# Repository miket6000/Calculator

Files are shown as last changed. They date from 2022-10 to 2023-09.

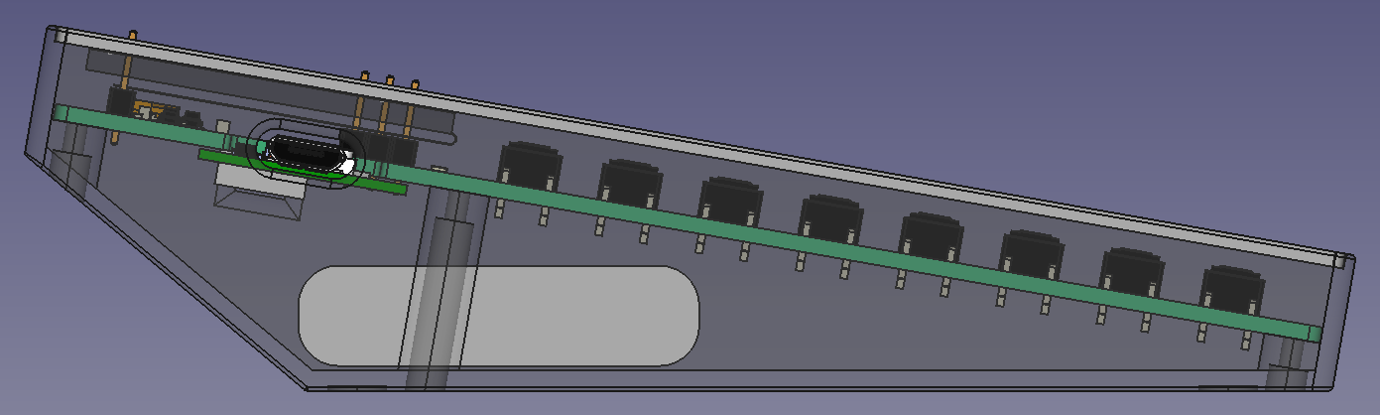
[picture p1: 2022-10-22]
LeftView.png

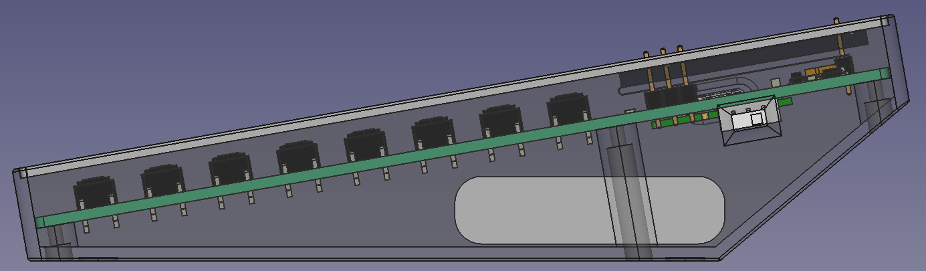
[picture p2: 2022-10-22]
RightView.png

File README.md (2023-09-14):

# Calculator
This calculator was built to scratch an itch. I wanted a physical RPN calculator similar to the excellent RealCalc. I also wanted an excuse to play around with a pi pico, particuarly their PIO. Finally I wanted a hardware platform to allow me to tinker in firmware and SW as I had ideas and wanted to try something out.

vanity shot

## Status
### Electrical
The PCB is great all circuits have been tested and I'm not aware of any issues. I'm very impressed with the OLED display (photographing it is hard). 

The pico's lowest standby power is only so-so, I can get down to about 980uA which with the 2500mA battery last around 3 months between charges if you only use standby and not the power switch (and significantly less time if the display is left on).

### Mechanical
The 3d printed enclosure and OLED support are perfectly functional, however I wouldn't mind adding more support in the center of the PCB to help dampen some of the button click noise. 

The front panel is a little iffy. The text is too small to easily read, there's not really enough room to make it larger. I also didn't properly consider the mounting so while I did design it with an assembly method in mind, and it does work, there's room for improvement.

### Software
The software is in a good demonstration state. Standby has been implemented to allow low power measurements. The display drivers and basic screen & keyboard abstraction layers have been created as has the skelaton of the ALU. So today you can use it as a basic pocket calculator. This is only a fraction of what I had planned though. 

I wanted to create a macro system so you could record common equations and adjust the variables you want. There's also a softkey function which so far is barely implemented. One softkey is used to put the calculator into standby, the others need defining and a proper system for assigning actions to the soft keys needs to be built.

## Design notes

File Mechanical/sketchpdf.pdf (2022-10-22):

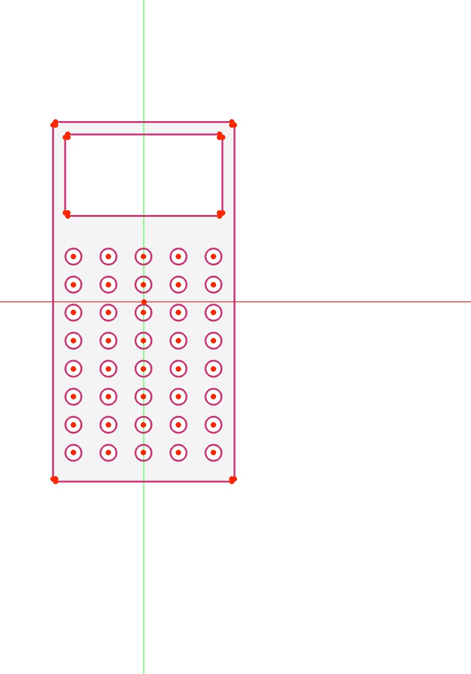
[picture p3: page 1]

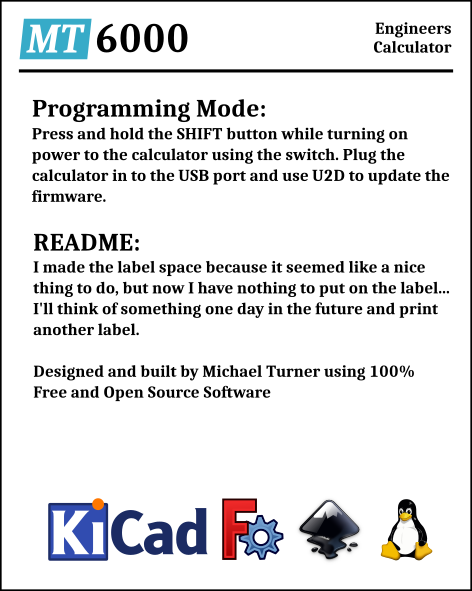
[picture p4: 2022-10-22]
Mechanical/Label.png

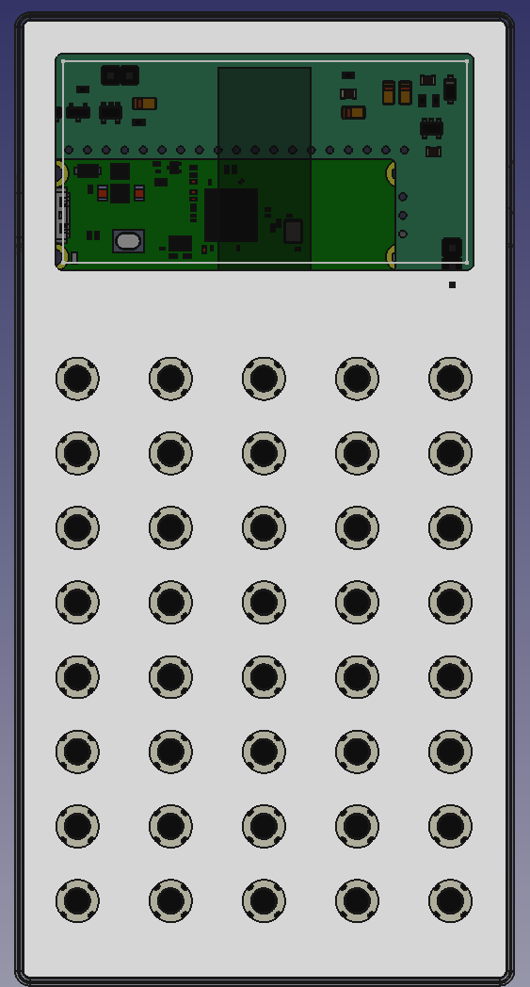
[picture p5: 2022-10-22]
FrontView.png

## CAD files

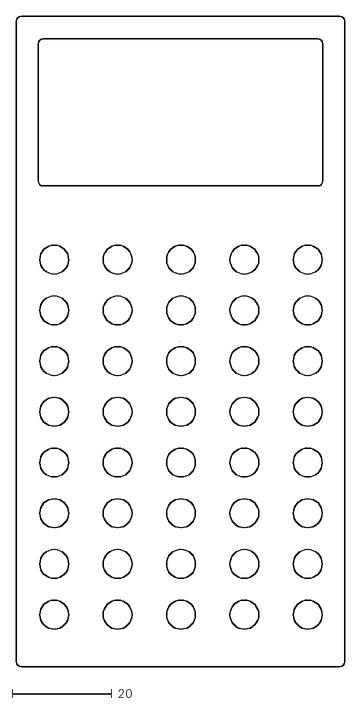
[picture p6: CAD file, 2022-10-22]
FrontPanel/outline.dxf
65.8 x 130.3

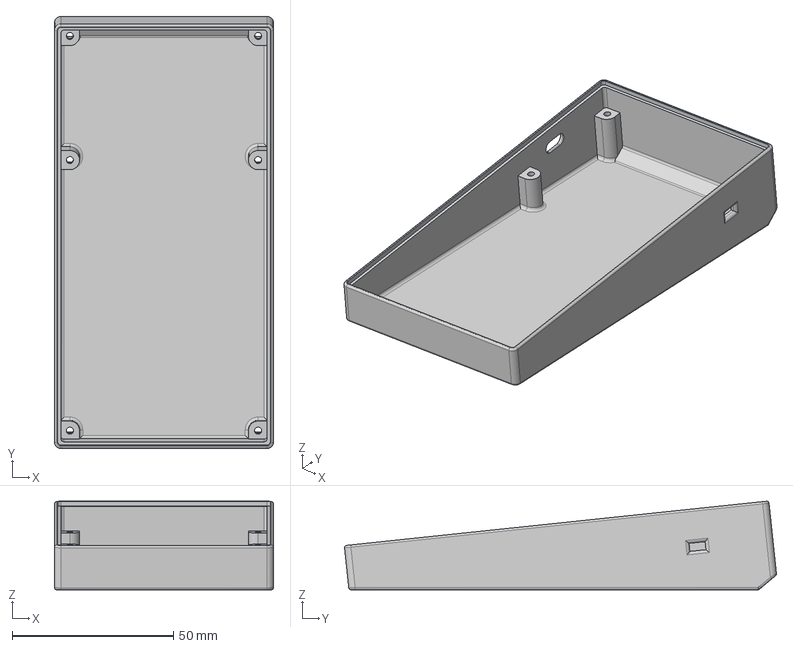
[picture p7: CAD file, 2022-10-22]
Mechanical/Calculator-Housing.step
68.0 x 134.1 x 27.5 mm

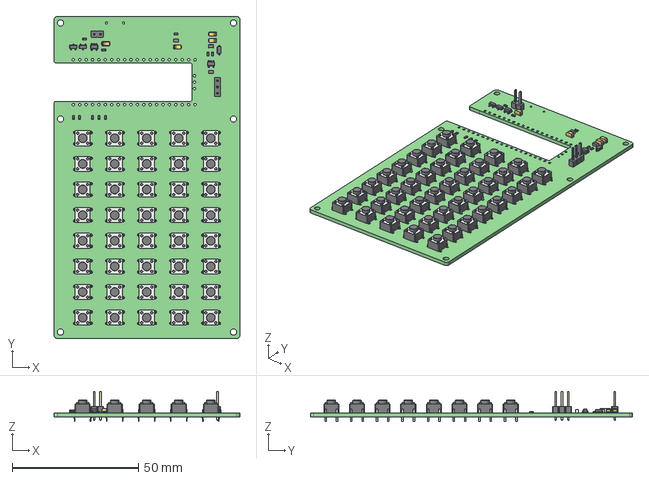
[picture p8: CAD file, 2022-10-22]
ThinCalculator.step
73.7 x 127.6 x 12.0 mm
_autosave-ThinCalculator PCB

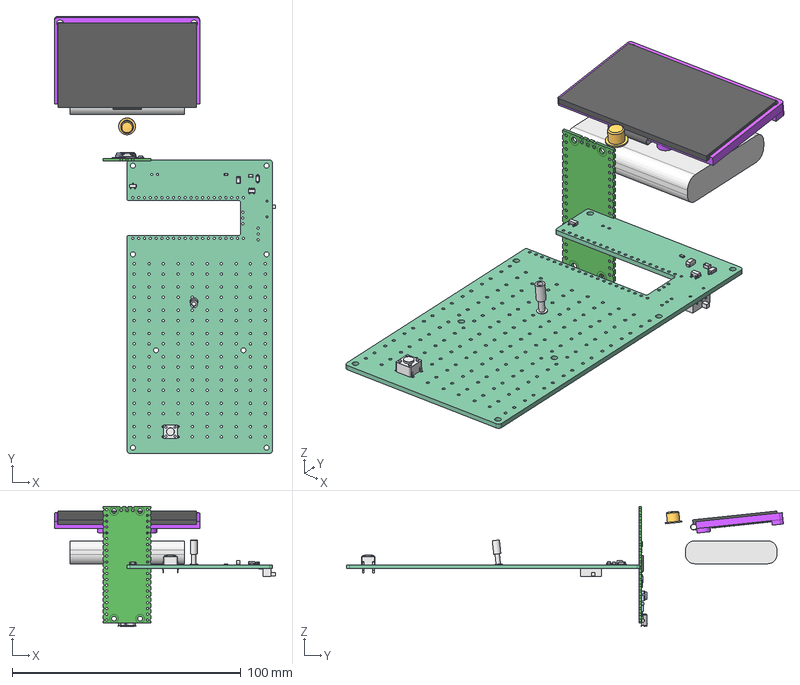
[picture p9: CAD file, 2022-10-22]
Mechanical/Calculator.FCStd
96.6 x 190.9 x 52.4 mm
Screen
Button
Screw
Battery
Standoff
ScreenSupport
PCB, Raspberry Pi Pico-R3
MicroUSB Port, Raspberry Pi Pico-R3
MicroUSB Port, Raspberry Pi Pico-R004
MicroUSB Port, Raspberry Pi Pico-R005
MicroUSB Port, Raspberry Pi Pico-R006
MicroUSB Port, Raspberry Pi Pico-R007
MicroUSB Port, Raspberry Pi Pico-R008
MicroUSB Port, Raspberry Pi Pico-R009
RP2040 Microcontroller, Raspberry Pi Pico-R3
SW1, Tact Switch, Raspberry Pi Pico-R3
D1, Diode, Schottky, Raspberry Pi Pico-R3
D2, QSME-C194, LED, Raspberry Pi Pico-R3
L1, Inductor, Raspberry Pi Pico-R3
U2, RT6150B-33GQW, Buck Boost Converter, Raspberry Pi Pico-R3
U3, W25Q16JVUXIQ, Serial NOR Flash 16 Mbit, Raspberry Pi Pico-R3
Q1, MOSFET, DMG1012T, Raspberry Pi Pico-R3
X1, X12M000000S096, 12 Mhz Crystal Resonator, Raspberry Pi Pico-R3
SMD Resistor, Configurable, Raspberry Pi Pico-R3_R1
SMD Resistor, Configurable, Raspberry Pi Pico-R3_R002
SMD Resistor, Configurable, Raspberry Pi Pico-R3_R003
SMD Resistor, Configurable, Raspberry Pi Pico-R3_R2
SMD Resistor, Configurable, Raspberry Pi Pico-R3_R005
SMD Resistor, Configurable, Raspberry Pi Pico-R3_R006
SMD Resistor, Configurable, Raspberry Pi Pico-R3_R3
SMD Resistor, Configurable, Raspberry Pi Pico-R3_R008
SMD Resistor, Configurable, Raspberry Pi Pico-R3_R009
SMD Resistor, Configurable, Raspberry Pi Pico-R3_R4
SMD Resistor, Configurable, Raspberry Pi Pico-R3_R011
SMD Resistor, Configurable, Raspberry Pi Pico-R3_R012
SMD Resistor, Configurable, Raspberry Pi Pico-R3_R5
SMD Resistor, Configurable, Raspberry Pi Pico-R3_R014
SMD Resistor, Configurable, Raspberry Pi Pico-R3_R015
SMD Resistor, Configurable, Raspberry Pi Pico-R3_R6
SMD Resistor, Configurable, Raspberry Pi Pico-R3_R017
SMD Resistor, Configurable, Raspberry Pi Pico-R3_R018
SMD Resistor, Configurable, Raspberry Pi Pico-R3_R7
SMD Resistor, Configurable, Raspberry Pi Pico-R3_R020
SMD Resistor, Configurable, Raspberry Pi Pico-R3_R021
SMD Resistor, Configurable, Raspberry Pi Pico-R3_R8
SMD Resistor, Configurable, Raspberry Pi Pico-R3_R023
SMD Resistor, Configurable, Raspberry Pi Pico-R3_R024
SMD Resistor, Configurable, Raspberry Pi Pico-R3_R9
SMD Resistor, Configurable, Raspberry Pi Pico-R3_R026
SMD Resistor, Configurable, Raspberry Pi Pico-R3_R027
SMD Resistor, Configurable, Raspberry Pi Pico-R3_R10
SMD Resistor, Configurable, Raspberry Pi Pico-R3_R029
SMD Resistor, Configurable, Raspberry Pi Pico-R3_R030
SMD Resistor, Configurable, Raspberry Pi Pico-R3_R11
SMD Resistor, Configurable, Raspberry Pi Pico-R3_R032
SMD Resistor, Configurable, Raspberry Pi Pico-R3_R033
SMD Resistor, Configurable, Raspberry Pi Pico-R3_R12
SMD Resistor, Configurable, Raspberry Pi Pico-R3_R035
SMD Resistor, Configurable, Raspberry Pi Pico-R3_R036
SMD Resistor, Configurable, Raspberry Pi Pico-R3_R13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

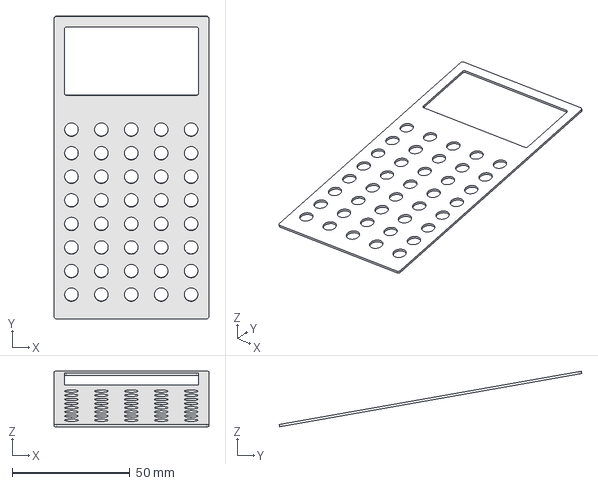
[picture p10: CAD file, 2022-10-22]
Mechanical/Calculator-FrontPlate-3d.step
65.8 x 128.5 x 23.6 mm

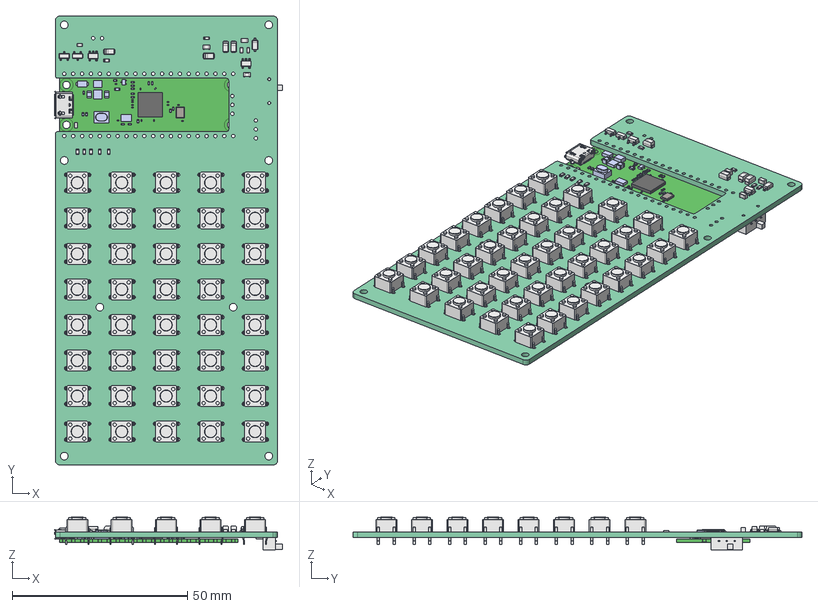
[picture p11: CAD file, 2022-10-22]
Mechanical/PCB.FCStd
65.1 x 128.3 x 9.40 mm
Pcb_a7a6
SW17_SW_PUSH_6mm_43fd921cdfa0 x 40
R4_R_0603_1608Metric_3d18a8aec7f1 x 10
Q2_SOT_23_d4db66b0a1e8 x 2
C4_CP_EIA_3216_18_Kemet_A_900fc9777db4 x 4
D1_D_SOD_123_bdbf39ab4f5c
U1_SOT_23_5_27f7c078fd10 x 2
C2_C_0805_2012Metric_c776970a00c4 x 3
PCB, Raspberry Pi Pico-R3
MicroUSB Port, Raspberry Pi Pico-R3
MicroUSB Port, Raspberry Pi Pico-R004
MicroUSB Port, Raspberry Pi Pico-R005
MicroUSB Port, Raspberry Pi Pico-R006
MicroUSB Port, Raspberry Pi Pico-R007
MicroUSB Port, Raspberry Pi Pico-R008
MicroUSB Port, Raspberry Pi Pico-R009
RP2040 Microcontroller, Raspberry Pi Pico-R3
SW1, Tact Switch, Raspberry Pi Pico-R3
D1, Diode, Schottky, Raspberry Pi Pico-R3
D2, QSME-C194, LED, Raspberry Pi Pico-R3
L1, Inductor, Raspberry Pi Pico-R3
U2, RT6150B-33GQW, Buck Boost Converter, Raspberry Pi Pico-R3
U3, W25Q16JVUXIQ, Serial NOR Flash 16 Mbit, Raspberry Pi Pico-R3
Q1, MOSFET, DMG1012T, Raspberry Pi Pico-R3
X1, X12M000000S096, 12 Mhz Crystal Resonator, Raspberry Pi Pico-R3
SMD Resistor, Configurable, Raspberry Pi Pico-R3_R1
SMD Resistor, Configurable, Raspberry Pi Pico-R3_R002
SMD Resistor, Configurable, Raspberry Pi Pico-R3_R003
SMD Resistor, Configurable, Raspberry Pi Pico-R3_R2
SMD Resistor, Configurable, Raspberry Pi Pico-R3_R005
SMD Resistor, Configurable, Raspberry Pi Pico-R3_R006
SMD Resistor, Configurable, Raspberry Pi Pico-R3_R3
SMD Resistor, Configurable, Raspberry Pi Pico-R3_R008
SMD Resistor, Configurable, Raspberry Pi Pico-R3_R009
SMD Resistor, Configurable, Raspberry Pi Pico-R3_R4
SMD Resistor, Configurable, Raspberry Pi Pico-R3_R011
SMD Resistor, Configurable, Raspberry Pi Pico-R3_R012
SMD Resistor, Configurable, Raspberry Pi Pico-R3_R5
SMD Resistor, Configurable, Raspberry Pi Pico-R3_R014
SMD Resistor, Configurable, Raspberry Pi Pico-R3_R015
SMD Resistor, Configurable, Raspberry Pi Pico-R3_R6
SMD Resistor, Configurable, Raspberry Pi Pico-R3_R017
SMD Resistor, Configurable, Raspberry Pi Pico-R3_R018
SMD Resistor, Configurable, Raspberry Pi Pico-R3_R7
SMD Resistor, Configurable, Raspberry Pi Pico-R3_R020
SMD Resistor, Configurable, Raspberry Pi Pico-R3_R021
SMD Resistor, Configurable, Raspberry Pi Pico-R3_R8
SMD Resistor, Configurable, Raspberry Pi Pico-R3_R023
SMD Resistor, Configurable, Raspberry Pi Pico-R3_R024
SMD Resistor, Configurable, Raspberry Pi Pico-R3_R9
SMD Resistor, Configurable, Raspberry Pi Pico-R3_R026
SMD Resistor, Configurable, Raspberry Pi Pico-R3_R027
SMD Resistor, Configurable, Raspberry Pi Pico-R3_R10
SMD Resistor, Configurable, Raspberry Pi Pico-R3_R029
SMD Resistor, Configurable, Raspberry Pi Pico-R3_R030
SMD Resistor, Configurable, Raspberry Pi Pico-R3_R11
SMD Resistor, Configurable, Raspberry Pi Pico-R3_R032
SMD Resistor, Configurable, Raspberry Pi Pico-R3_R033
SMD Resistor, Configurable, Raspberry Pi Pico-R3_R12
SMD Resistor, Configurable, Raspberry Pi Pico-R3_R035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

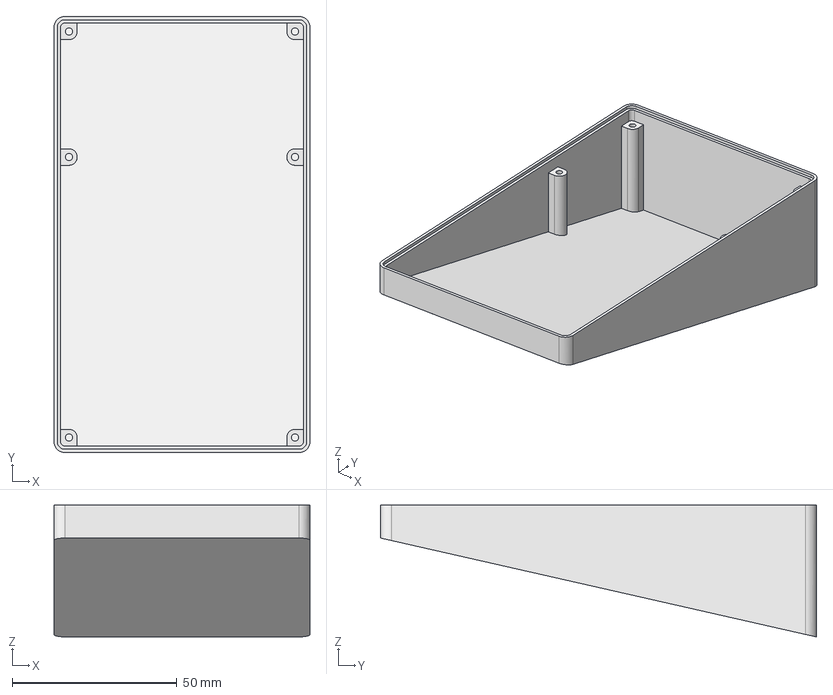
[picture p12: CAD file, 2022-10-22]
Mechanical/CalculatorBody.FCStd
77.7 x 132.3 x 40.0 mm

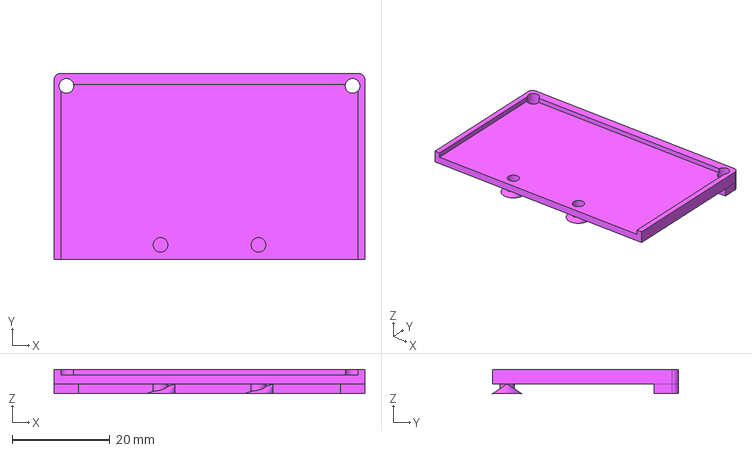
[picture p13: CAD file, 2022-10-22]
Mechanical/Calculator-ScreenSupport.step
63.5 x 38.0 x 5.00 mm

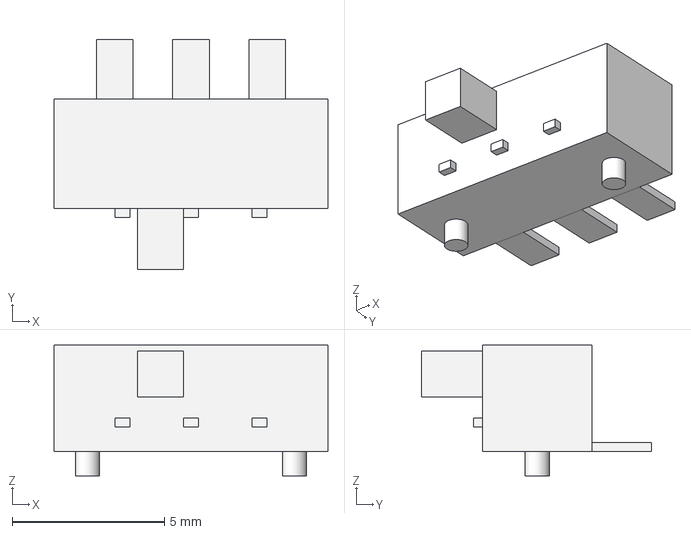
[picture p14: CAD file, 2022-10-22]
Mechanical/JS102011SAQN.step
9.00 x 7.55 x 4.30 mm

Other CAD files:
Mechanical/Calculator-ScreenSupport.stl
Mechanical/JS102011SAQN.FCStd

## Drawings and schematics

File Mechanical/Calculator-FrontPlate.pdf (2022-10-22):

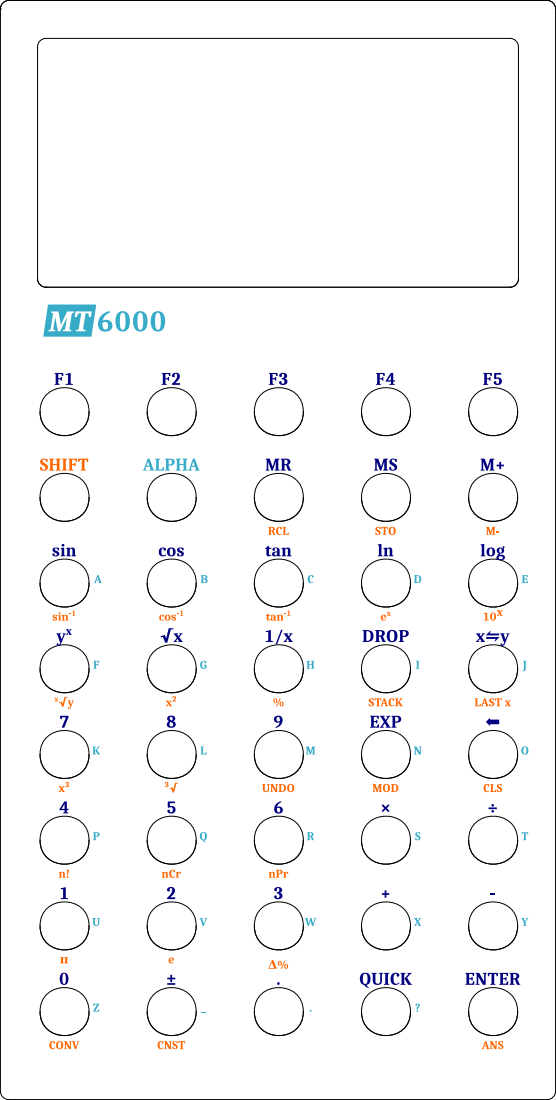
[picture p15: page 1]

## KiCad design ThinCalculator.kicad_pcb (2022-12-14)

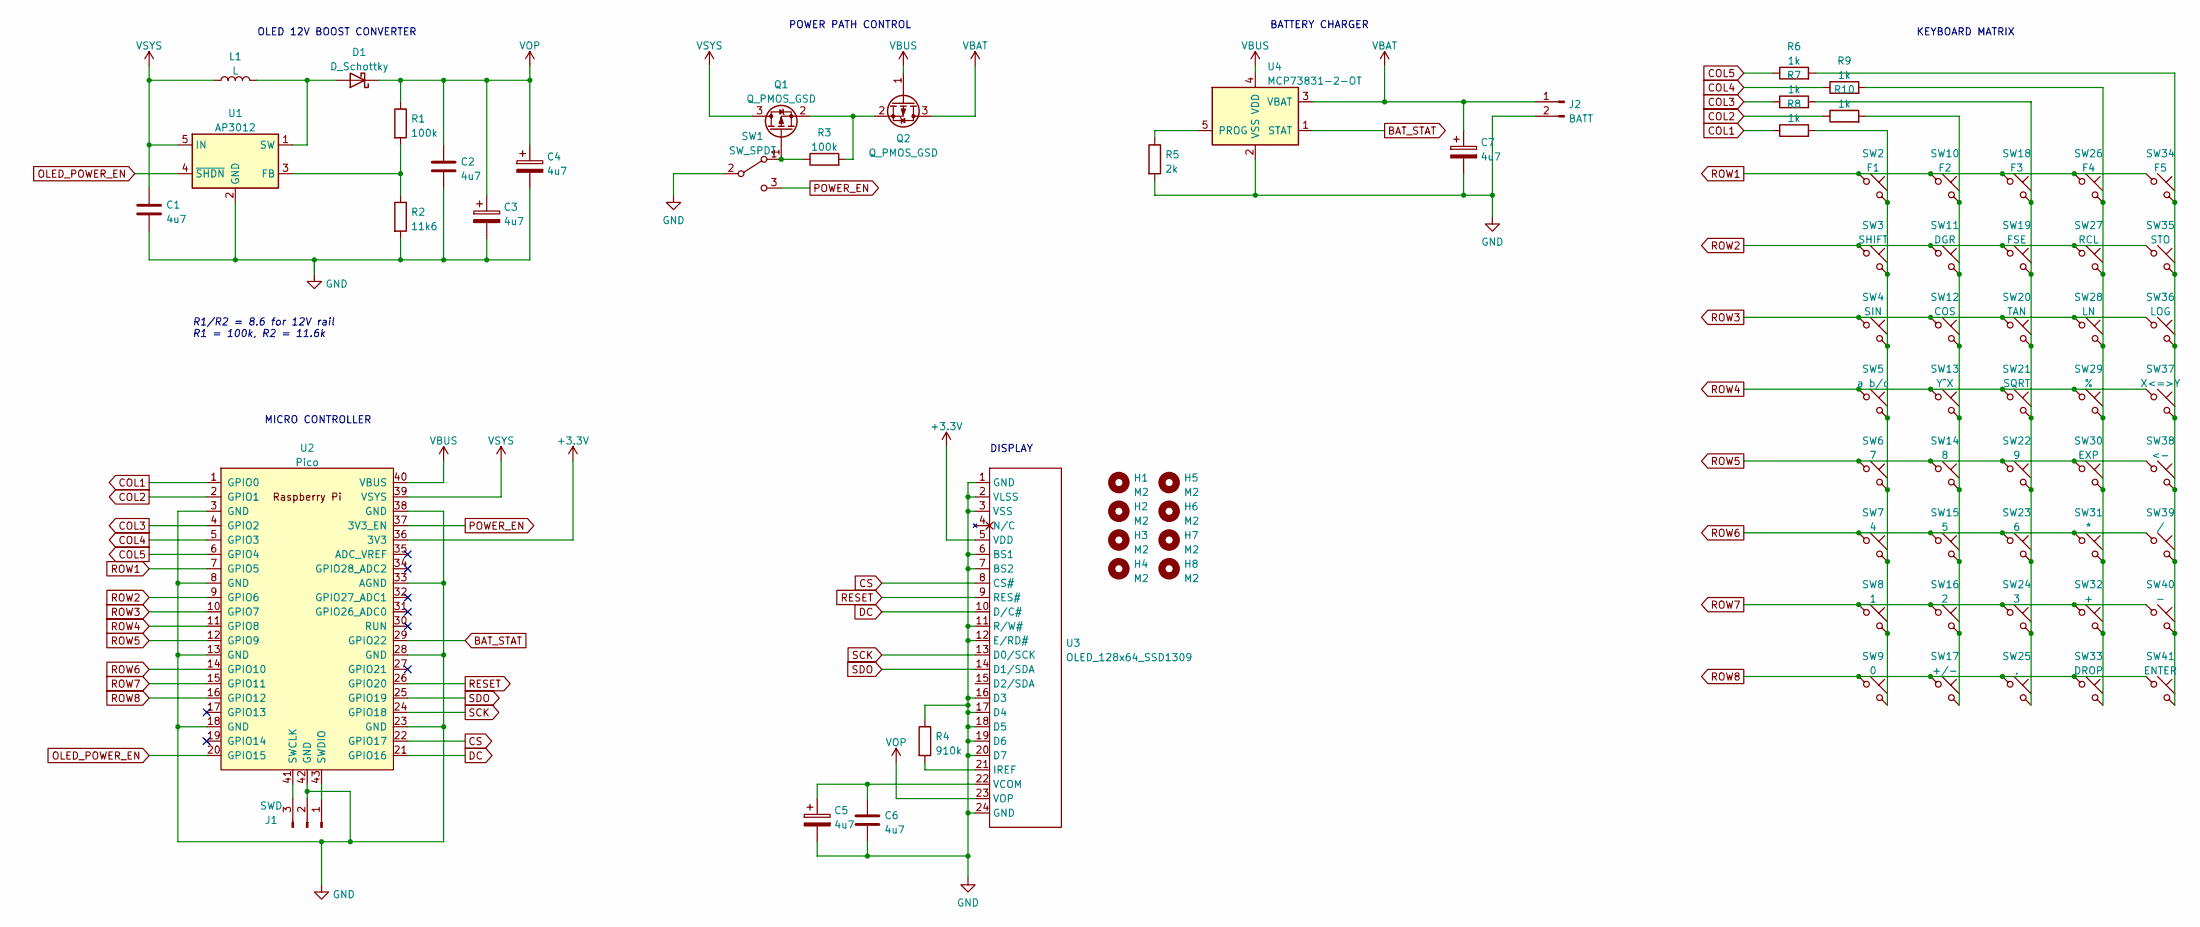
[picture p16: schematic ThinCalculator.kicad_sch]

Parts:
C1, C2, C6: 4u7; C_0805_2012Metric_Pad1.18x1.45mm_HandSolder
C3, C4, C5, C7: 4u7; CP_EIA-3216-18_Kemet-A_Pad1.58x1.35mm_HandSolder
D1: D_Schottky; D_SOD-123
H1, H2, H3, H4, H5, H6, H7, H8: M2; MountingHole_2.2mm_M2_ISO7380
J1: SWD; PinHeader_1x03_P2.54mm_Vertical
J2: BATT; JST_EH_S2B-EH_1x02_P2.50mm_Horizontal
L1: L; L_Taiyo-Yuden_NR-30xx_HandSoldering
Q1, Q2: Q_PMOS_GSD; SOT-23
R1, R3: 100k; R_0603_1608Metric_Pad0.98x0.95mm_HandSolder
R2: 11k6; R_0603_1608Metric_Pad0.98x0.95mm_HandSolder
R4: 910k; R_0603_1608Metric_Pad0.98x0.95mm_HandSolder
R5: 2k; R_0603_1608Metric_Pad0.98x0.95mm_HandSolder
R6, R7, R8, R9, R10: 1k; R_0603_1608Metric_Pad0.98x0.95mm_HandSolder
SW1: SW_SPDT; SW_SPDT_CK-JS102011SAQN
SW2: F1; SW_PUSH_6mm
SW3: SHIFT; SW_PUSH_6mm
SW4: SIN; SW_PUSH_6mm
SW5: a b/c; SW_PUSH_6mm
SW6: 7; SW_PUSH_6mm
SW7: 4; SW_PUSH_6mm
SW8: 1; SW_PUSH_6mm
SW9: 0; SW_PUSH_6mm
SW10: F2; SW_PUSH_6mm
SW11: DGR; SW_PUSH_6mm
SW12: COS; SW_PUSH_6mm
SW13: Y^X; SW_PUSH_6mm
SW14: 8; SW_PUSH_6mm
SW15: 5; SW_PUSH_6mm
SW16: 2; SW_PUSH_6mm
SW17: +/-; SW_PUSH_6mm
SW18: F3; SW_PUSH_6mm
SW19: FSE; SW_PUSH_6mm
SW20: TAN; SW_PUSH_6mm
SW21: SQRT; SW_PUSH_6mm
SW22: 9; SW_PUSH_6mm
SW23: 6; SW_PUSH_6mm
SW24: 3; SW_PUSH_6mm
SW25: .; SW_PUSH_6mm
SW26: F4; SW_PUSH_6mm
SW27: RCL; SW_PUSH_6mm
SW28: LN; SW_PUSH_6mm
SW29: %; SW_PUSH_6mm
SW30: EXP; SW_PUSH_6mm
SW31: *; SW_PUSH_6mm
SW32: +; SW_PUSH_6mm
SW33: DROP; SW_PUSH_6mm
SW34: F5; SW_PUSH_6mm
SW35: STO; SW_PUSH_6mm
SW36: LOG; SW_PUSH_6mm
SW37: X<=>Y; SW_PUSH_6mm
SW38: <-; SW_PUSH_6mm
SW39: /; SW_PUSH_6mm
SW40: -; SW_PUSH_6mm
SW41: ENTER; SW_PUSH_6mm
U1: AP3012; SOT-23-5
U2: Pico; RPi_Pico_SMD_TH__Reverse_Mount
U3: OLED_128x64_SSD1309; Hirose_FH12-24S-0.5SH_1x24-1MP_P0.50mm_Horizontal
U4: MCP73831-2-OT; SOT-23-5

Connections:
+3V3: U2.36 (3V3), U3.5 (VDD)
BAT_STAT: U2.29 (GPIO22), U4.1 (STAT)
COL1: R8.1, U2.1 (GPIO0)
COL2: R10.1, U2.2 (GPIO1)
COL3: R7.1, U2.4 (GPIO2)
COL4: R9.1, U2.5 (GPIO3)
COL5: R6.1, U2.6 (GPIO4)
CS: U2.22 (GPIO17), U3.8 (CS#)
DC: U2.21 (GPIO16), U3.10 (D/C#)
GND: C1.2, C2.2, C3.2, C4.2, C5.2, C6.2, C7.2, J1.2, J2.2, R2.2, R4.1, R5.2, SW1.2 (B), U1.2 (GND), U2.3 (GND), U2.8 (GND), U2.13 (GND), U2.18 (GND), U2.23 (GND), U2.28 (GND), U2.33 (AGND), U2.38 (GND), U2.42 (GND), U3.1 (GND), U3.2 (VLSS), U3.3 (VSS), U3.6 (BS1), U3.7 (BS2), U3.11 (R/W#), U3.12 (E/RD#), U3.16 (D3), U3.17 (D4), U3.18 (D5), U3.19 (D6), U3.20 (D7), U3.24 (GND), U4.2 (VSS)
unnamed: C5.1, C6.1, U3.22 (VCOM)
unnamed: D1.2 (A), L1.2, U1.1 (SW)
unnamed: J1.1, U2.43 (SWDIO)
unnamed: J1.3, U2.41 (SWCLK)
unnamed: Q1.1 (G), R3.1, SW1.1 (A)
unnamed: Q1.2 (S), Q2.2 (S), R3.2
unnamed: R1.2, R2.1, U1.3 (FB)
unnamed: R4.2, U3.21 (IREF)
unnamed: R5.1, U4.5 (PROG)
unnamed: R6.2, SW34.2, SW35.2, SW36.2, SW37.2, SW38.2, SW39.2, SW40.2, SW41.2
unnamed: R7.2, SW18.2, SW19.2, SW20.2, SW21.2, SW22.2, SW23.2, SW24.2, SW25.2
unnamed: R8.2, SW2.2, SW3.2, SW4.2, SW5.2, SW6.2, SW7.2, SW8.2, SW9.2
unnamed: R9.2, SW26.2, SW27.2, SW28.2, SW29.2, SW30.2, SW31.2, SW32.2, SW33.2
unnamed: R10.2, SW10.2, SW11.2, SW12.2, SW13.2, SW14.2, SW15.2, SW16.2, SW17.2
OLED_POWER_EN: U1.4 (~SHDN), U2.20 (GPIO15)
POWER_EN: SW1.3 (C), U2.37 (3V3_EN)
RESET: U2.26 (GPIO20), U3.9 (RES#)
ROW1: SW2.1, SW10.1, SW18.1, SW26.1, SW34.1, U2.7 (GPIO5)
ROW2: SW3.1, SW11.1, SW19.1, SW27.1, SW35.1, U2.9 (GPIO6)
ROW3: SW4.1, SW12.1, SW20.1, SW28.1, SW36.1, U2.10 (GPIO7)
ROW4: SW5.1, SW13.1, SW21.1, SW29.1, SW37.1, U2.11 (GPIO8)
ROW5: SW6.1, SW14.1, SW22.1, SW30.1, SW38.1, U2.12 (GPIO9)
ROW6: SW7.1, SW15.1, SW23.1, SW31.1, SW39.1, U2.14 (GPIO10)
ROW7: SW8.1, SW16.1, SW24.1, SW32.1, SW40.1, U2.15 (GPIO11)
ROW8: SW9.1, SW17.1, SW25.1, SW33.1, SW41.1, U2.16 (GPIO12)
SCK: U2.24 (GPIO18), U3.13 (D0/SCK)
SDO: U2.25 (GPIO19), U3.14 (D1/SDA)
VBAT: C7.1, J2.1, Q2.3 (D), U4.3 (VBAT)
VBUS: Q2.1 (G), U2.40 (VBUS), U4.4 (VDD)
VOP: C2.1, C3.1, C4.1, D1.1 (K), R1.1, U3.23 (VOP)
VSYS: C1.1, L1.1, Q1.3 (D), U1.5 (IN), U2.39 (VSYS)

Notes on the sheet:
MICRO CONTROLLER
POWER PATH CONTROL
OLED 12V BOOST CONVERTER
DISPLAY
BATTERY CHARGER
R1/R2 = 8.6 for 12V rail R1 = 100k, R2 = 11.6k
KEYBOARD MATRIX

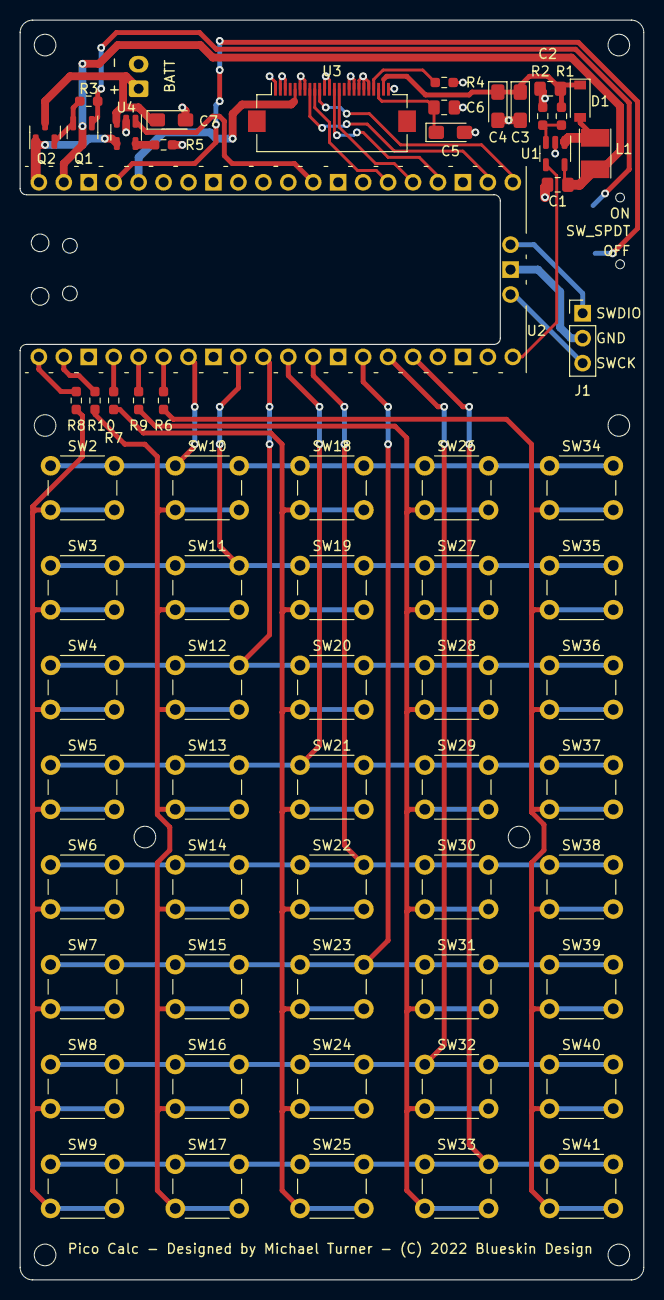
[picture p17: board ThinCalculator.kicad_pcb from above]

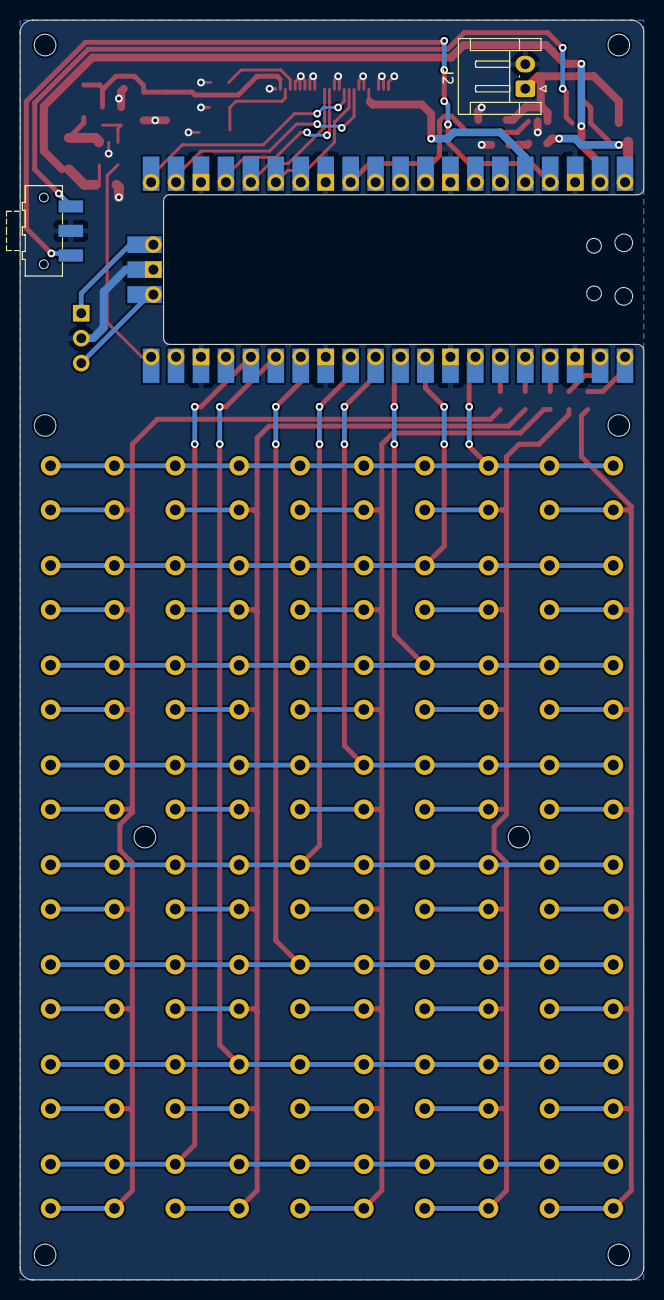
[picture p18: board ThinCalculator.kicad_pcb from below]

Board: 2 copper layers, 63.5 x 128.3 mm, 76 parts (2 on the bottom side), 41 nets.

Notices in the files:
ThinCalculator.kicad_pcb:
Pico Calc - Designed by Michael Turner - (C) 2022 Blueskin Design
